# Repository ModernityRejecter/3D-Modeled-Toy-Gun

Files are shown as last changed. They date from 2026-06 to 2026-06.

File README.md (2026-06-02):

# 3D Printed Mechanical Blaster

A fully 3D-printable, **hammer-fired** mechanical toy blaster built around a two-piece press-fit case, a snap-locking side magazine, and **three entirely 3D-printed springs**. No metal hardware, no rubber bands - every functional part, including all springs, comes off the print bed.

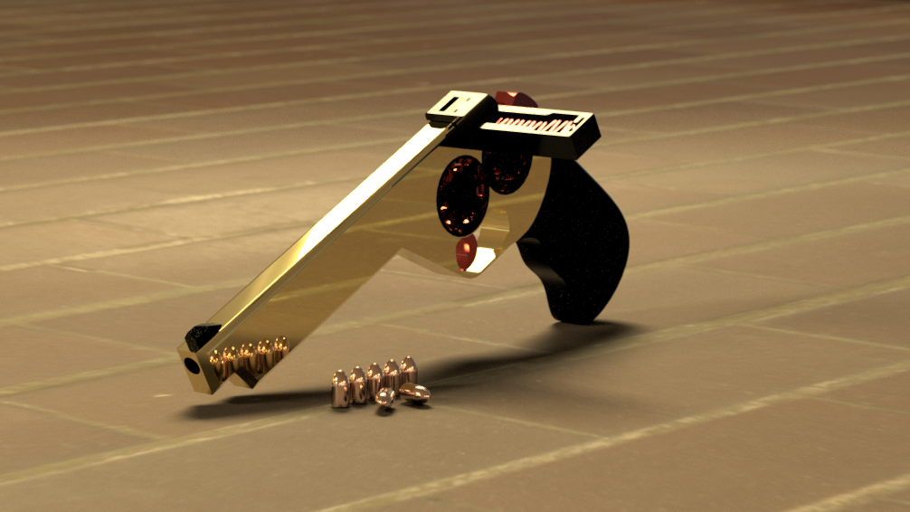
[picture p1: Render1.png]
Assembled blaster


## Project Description

This project is a hand-held, hammer-fired spring blaster that launches 3D-printed darts from a removable, spring-fed magazine. Energy is stored by winding a printed **spiral hammer spring**; pulling the trigger releases the hammer, which strikes a dart and fires it down the barrel. A printed **trigger-return spring** resets the trigger, and a printed **zig-zag magazine spring** feeds the next dart automatically.

What makes it notable: the entire mechanism - frame, barrel, hammer, trigger, magazine, darts, and **all three springs** - is 3D printed. The only thing between a spool of filament and a working blaster is print time and assembly.

The goal was to design a product that:
- **Serves a purpose** - IT'S FUN! It actually fires darts and reloads from a magazine, while doubling as a tactile fidget object.
- **Makes sense mechanically** - a wound spiral spring stores the firing energy; a sear/trigger releases it; a separate follower spring handles feeding.
- **Stays printable** - split into bed-friendly, snap-fit components with tuned tolerances so it prints with minimal supports.

## How It Works

The blaster's case is a **two-piece clamshell**, split along the centerline of the barrel into an **upper** and a **lower** half. Each half carries similar, mirrored features - half the barrel bore, the grip, and the internal cavities - and together they enclose the hammer, trigger and springs. The halves are held shut by **two snug press fits**, and a **detachable magazine** mounts on the side.

1. **Load the magazine.** Pull the follower down with your thumb and drop darts in through the skeletonized magazine's side feed-lips, against the zig-zag **magazine spring**, which keeps constant pressure so a fresh dart is always presented in line with the barrel.
2. **Insert the magazine.** It slides into the frame and a snap joint engages the upper case, locking it in place so it stays seated during firing until it is deliberately removed.
3. **Cock the hammer.** Cocking winds the spiral **hammer spring**, storing firing energy; a sear catches and holds the hammer.
4. **Fire.** Pulling the trigger releases the sear - the hammer snaps forward under the unwinding hammer spring and strikes the dart, launching it down the upper's barrel. The **trigger spring** returns the trigger to its resting position.
5. **Feed.** With the dart gone, the magazine spring advances the next dart into the barrel line. Because the magazine sits in-line as a *shoot-through breech*, there's no separate chambering step - it's ready to cock and fire again.

### Why it works
- **Spiral (clock-type) torsion springs** for the hammer and trigger store rotational energy compactly and spread the load along the whole coil - important for printed plastic, which takes a permanent set if a single section is over-stressed. Winding distributes strain so the spring survives repeated cycling.
- The **zig-zag magazine spring** is a linear, low-force accordion: long travel in a compact part, with gentle, consistent follower pressure that advances a dart without binding the feed.
- The **two-piece clamshell case** (split along the barrel centerline) lets the whole mechanism print support-free and gives full assembly access to the hammer, trigger and springs; the two halves then close over the internals with two snug press fits - no screws or glue.

## My Contribution & Design Philosophy

**The entire case - both the upper and the lower - is my own original creation, reimagined from the ground up.** The form factor, grip ergonomics, barrel layout, and the gold/black aesthetic are all mine; the case is not derived from any existing design.

What I drew from the two references below are the **functional building blocks**, which I then re-engineered so they could work *together* in one product:

- From the [**3D Printed Spring Blaster**](https://youtu.be/xOeDvl-vA04): the concept of a printed-spring-powered firing action, which I reworked into a wound spiral **hammer spring** plus a printed **trigger-return spring**.
- From the [**3D Printed Spring Gun with working Magazine**](https://youtu.be/UC8Zp1ZFvpY): the removable, spring-fed **magazine** and its zig-zag follower spring.

So the heavily-inspired elements are limited to the **three springs and the magazine** - everything that houses and connects them is original. Making a hammer-driven action and an auto-feeding magazine coexist meant rethinking how the hammer, sear, feed path, and three springs interact, since each reference solved only one half of the problem.

A detail I'm particularly proud of: **the magazine locks in place via a snap joint that engages the upper case** when inserted. It stays firmly seated during firing and only releases when deliberately removed - no wobble and no metal catch, fully printed.

## Design Journey

The final design is the result of real iteration. Two decisions shaped it more than any other: **how darts feed**, and **how the magazine stays locked**.

### Feeding system: from gravity hopper to side-mounted magazine

The first question was how to get a dart into the chamber. Several approaches were considered:

- **Vertical gravity hopper** - ruled out early. Hoppers are notoriously unreliable: tilt the blaster sideways or let darts clump together and gravity stops feeding, causing dry-fires. Worse, without constant pressure a dart can fall into the chamber half-seated just as the hammer swings forward, crushing it and jamming the action. A bulky top-mounted container would also have hidden the exposed spiral torsion spring that gives the blaster its mechanical character.
- **Bottom-feeding magazine** - rejected because it needs a complex transfer / lifter bar to raise rounds up to the barrel.
- **Horizontal feeding** - the winner. The choice came down to a sliding "harmonica" block versus a side-mounted ("Sten-style") magazine, and I went with the **side-mounted magazine**. It was worth troubleshooting the spring tension in exchange for the cool factor and the mechanical simplicity it unlocked: the swinging hammer doubles as **both the firing pin and the block that holds the next dart back**.

**The breakthrough** was treating the magazine as a physical extension of the barrel - a "shoot-through" / nested-breech layout. The dart fires straight through the magazine's feed position, which completely eliminates the need for a separate chambering mechanism.

**A course correction:** I first planned to reload darts backward through the front barrel hole of the magazine, but the geometry won't allow pushing darts in against the follower spring's pressure. The fix was a **skeletonized magazine** - open sides let you pull the follower down with your thumb and drop darts straight in through the side feed-lips.

### Magazine catch: from flex-latch to snap joint

With the magazine on the side, it had to stay put during firing. Three options were on the table:

- a **compliant flex-latch** (a printed living-hinge clip),
- a **manual pin** (padlock-style), and
- a simple **friction bump**.

The flex-latch was the most "engineered" route, and I even considered a durability trick: embedding a short piece of raw, unprinted **filament** as the bump so it would survive thousands of reloads without the plastic wearing down. In the end, though, the flex-latch/bump approach would have introduced **printing problems and a lot of support material for minimal gain**. So I swapped it for the **snap joint** the magazine uses today - it engages the upper case directly, locks firmly during firing, releases by hand, and prints cleanly with no supports.

## Renders

| | |
|---|---|
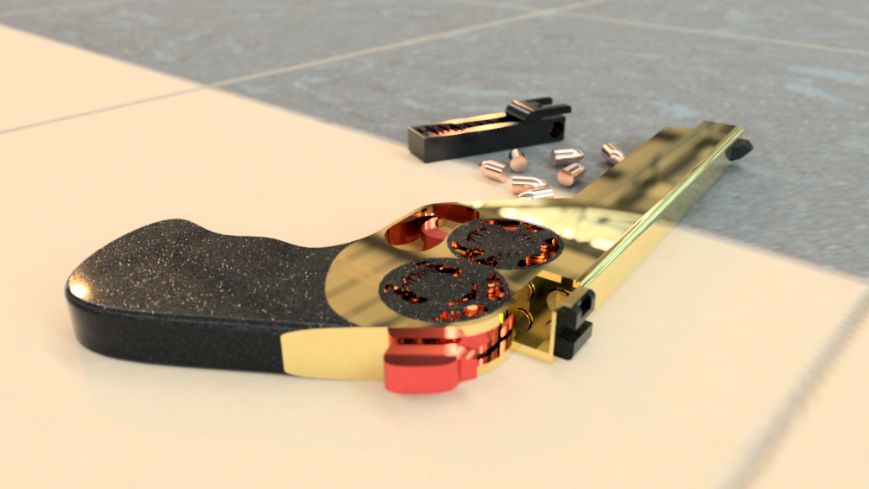
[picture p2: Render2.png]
Render 2
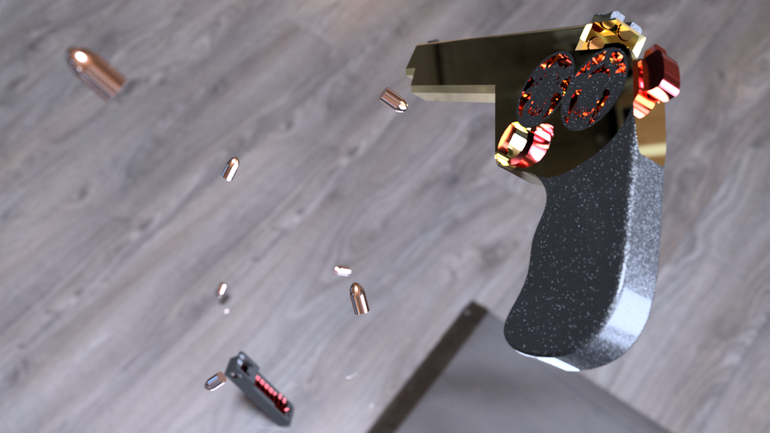
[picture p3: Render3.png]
Render 3
|  |  |

## Components & Parts

Every part is 3D printed. The mechanism comprises **7 unique components** (some printed in multiples), grouped below by the G-code file they belong to.

| Render | Component | Purpose | Print file |
|:---:|---|---|---|
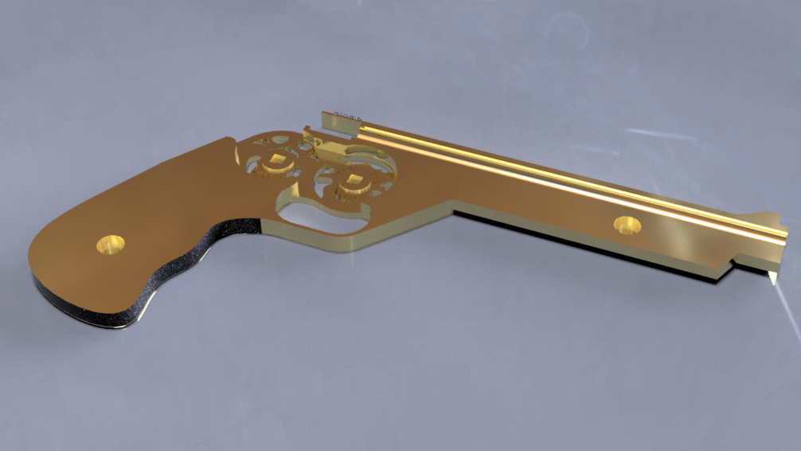
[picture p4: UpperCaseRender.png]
|  | **Upper case** | One half of the clamshell case (split along the barrel centerline). Carries half the barrel bore, grip and internal cavities, and encloses the hammer, trigger and springs together with the lower half. | `UpperCase.gcode` |
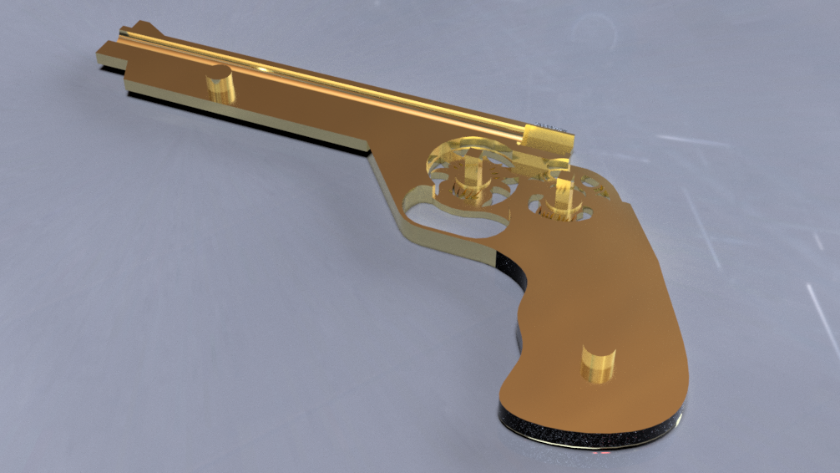
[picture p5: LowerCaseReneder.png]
|  | **Lower case** | The matching case half, with the mirrored half of the barrel, grip and trigger guard. Holds the hammer and trigger springs and accepts the side magazine; mates to the upper half via two snug press fits. | `LowerCase+TorsionSprings.gcode` |
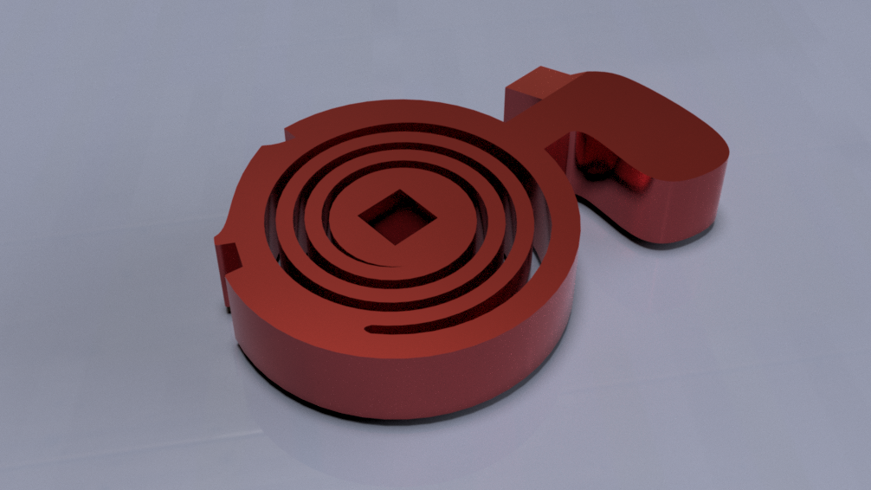
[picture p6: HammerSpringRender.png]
|  | **Hammer spring** | Spiral torsion spring with a square center mount. Wound during cocking; drives the hammer forward to strike the dart. | `LowerCase+TorsionSprings.gcode` |
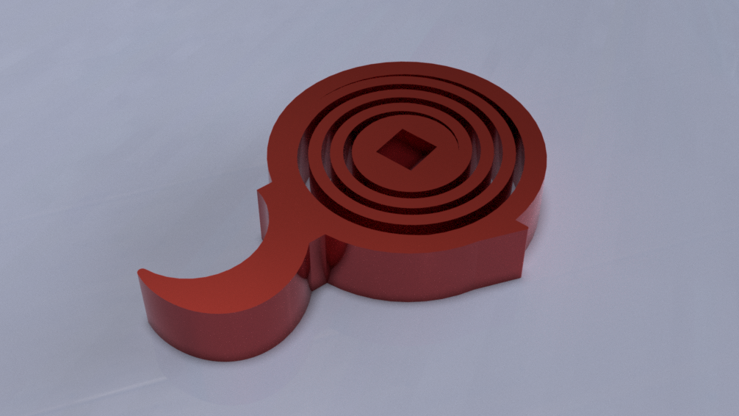
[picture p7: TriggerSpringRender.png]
|  | **Trigger spring** | Smaller spiral torsion spring; returns the trigger to its resting position and keeps the sear engaged. | `LowerCase+TorsionSprings.gcode` |
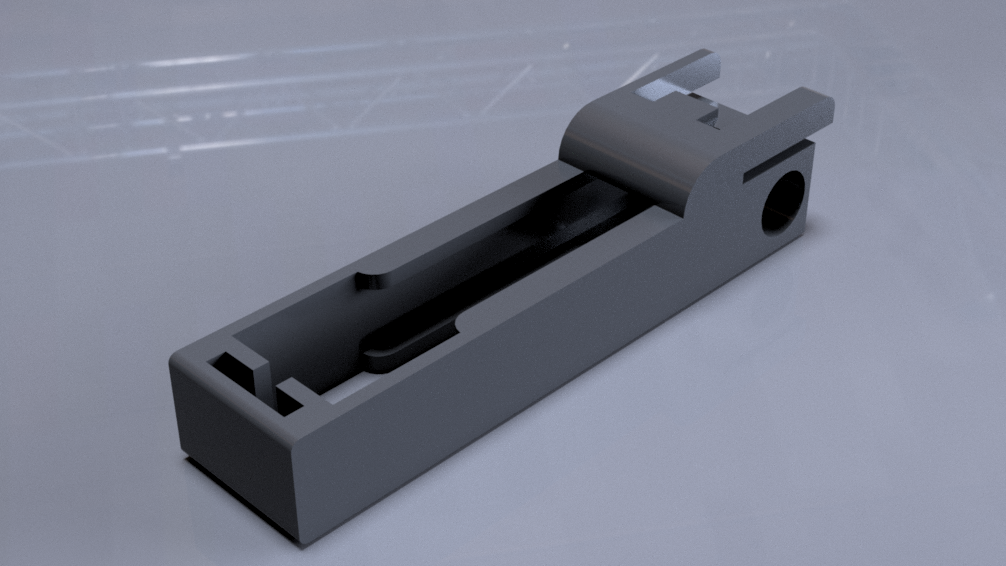
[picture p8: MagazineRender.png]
|  | **Magazine** | Detachable box magazine; holds the dart stack and guides rounds up to the feed position. Locks into the upper case via a snap joint when inserted. | `Darts+Mag+MagSpring.gcode` |
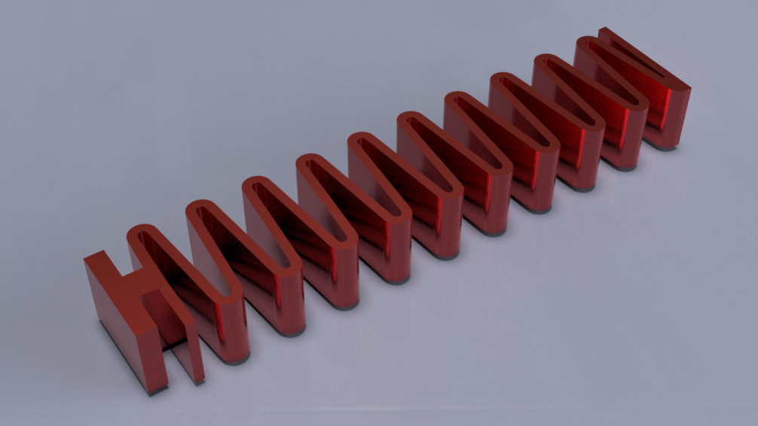
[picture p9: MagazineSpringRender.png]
|  | **Magazine spring** | Zig-zag (accordion) compression spring; the follower that pushes darts toward the chamber. | `Darts+Mag+MagSpring.gcode` |
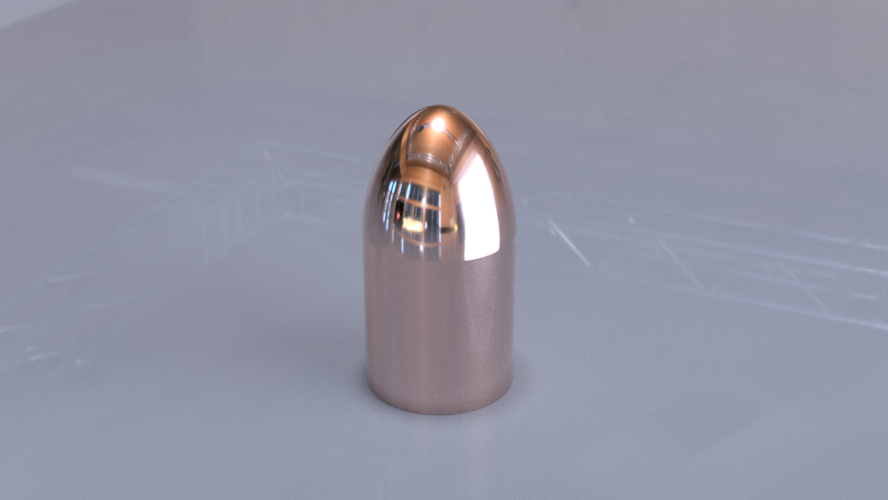
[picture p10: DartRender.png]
|  | **Dart** | The bullet-shaped projectile that the hammer strikes and launches. Printed in multiples. | `Darts+Mag+MagSpring.gcode` |

## Printability

The model was designed to be printed **without metal hardware or rubber bands, and with minimal supports**:

- **Split into bed-friendly components** - upper, lower, magazine, the three springs, and darts print separately so each fits a standard build plate and prints in its strongest orientation.
- **Press-fit + snap-fit assembly** - the two case halves hold together with two snug press fits and the magazine snap-locks to the case; no screws or glue required.
- **Three fully-printed springs** - the spiral hammer and trigger springs and the zig-zag magazine spring are the centerpiece of the printability story: their wall thicknesses and gaps are tuned so the plastic flexes and stores energy without snapping.
- **Tolerances** - mating/moving surfaces include clearance for FDM tolerances so the action moves freely straight off the printer.
- **Edges chamfered/filleted** for strength and to ease first-layer adhesion and part insertion.

## Video Showcase

▶️ **[Watch the assembly guide + motion-study showcase on YouTube](https://youtu.be/Alt_Uf0PqNY)**

Watch the demo (https://youtu.be/Alt_Uf0PqNY)

The video walks through how the blaster goes together and plays the Fusion 360 motion study, showing the hammer, trigger, and magazine feed in action.

## Project Files

| File | Description |
|---|---|
| [`ToyBlaster.f3d`](ToyBlaster.f3d) | Full Fusion 360 project (all components, sketches, joints, motion study) |
| [`ToyBlaster.stl`](ToyBlaster.stl) | Combined STL mesh of the model |
| [`UpperCase.gcode`](UpperCase.gcode) | Sliced G-code - upper / barrel |
| [`LowerCase+TorsionSprings.gcode`](LowerCase+TorsionSprings.gcode) | Sliced G-code - lower frame + hammer & trigger springs |
| [`Darts+Mag+MagSpring.gcode`](Darts+Mag+MagSpring.gcode) | Sliced G-code - darts, magazine, and magazine spring |
| Assembly renders | [`Render1.png`](Render1.png) · [`Render2.png`](Render2.png) · [`Render3.png`](Render3.png) |
| Component renders | [`UpperCaseRender.png`](UpperCaseRender.png) · [`LowerCaseReneder.png`](LowerCaseReneder.png) · [`HammerSpringRender.png`](HammerSpringRender.png) · [`TriggerSpringRender.png`](TriggerSpringRender.png) · [`MagazineRender.png`](MagazineRender.png) · [`MagazineSpringRender.png`](MagazineSpringRender.png) · [`DartRender.png`](DartRender.png) |

## Inspiration & Resources

This project was inspired by the following designs. Click an image to watch it in action:

3D Printed Spring Blaster (https://youtu.be/xOeDvl-vA04?si=E-KsS5-ckZ77c3AA)
**[3D Printed Spring Blaster](https://youtu.be/xOeDvl-vA04?si=E-KsS5-ckZ77c3AA)** - **merged philosophy #1:** the printed-spring firing action.

3D Printed Spring Gun with working Magazine (https://youtu.be/UC8Zp1ZFvpY?si=vRvTGaYKZ4BDErI3)
**[3D Printed Spring Gun with working Magazine](https://youtu.be/UC8Zp1ZFvpY?si=vRvTGaYKZ4BDErI3)** - **merged philosophy #2:** the removable, spring-fed magazine.

3D Printed Fidget Gun (https://youtu.be/0uawUImH5NA?si=HxQGf2qJCjkDknKz)
**[3D Printed Fidget Gun](https://youtu.be/0uawUImH5NA?si=HxQGf2qJCjkDknKz)** - general inspiration for the tactile / fidget feel.

**Tools used:** Autodesk Fusion 360 (modeling, joints, motion study) · PrusaSlicer (G-code generation) · Google Gemini (design sounding-board for evaluating the feeding and magazine-catch options) · Claude (Anthropic) (structuring and polishing this README).

## Design Challenges & Lessons Learned

The hardest parts of this project were all about making fully-printed mechanics behave reliably:

- **Tuning the three printed springs** was the biggest iteration cost. Wall thickness, gap spacing, and coil count all had to be balanced so each spring flexes and stores energy without snapping or taking a permanent set after repeated cycling. The spiral hammer and trigger springs and the zig-zag magazine spring each needed their own tuning.
- **Dialing in the snap-joint magazine lock** meant hitting a tight tolerance window on an FDM printer: firm enough that the magazine stays locked to the upper case during firing, loose enough that it still releases by hand. Too tight and it won't seat; too loose and it rattles out.
- **Making the hammer action and magazine feed coexist** was the core mechanical problem - the hammer had to strike and clear the chamber on every cycle without the follower spring fouling its travel, which is what drove the internal layout and the placement of the three springs.
- **Designing for printability from the start** - splitting the model into bed-friendly, snap-fit parts and orienting each for strength and minimal supports - was far easier than trying to retrofit printability onto a finished design.

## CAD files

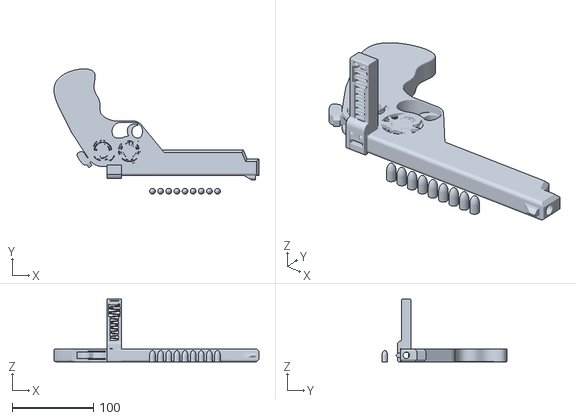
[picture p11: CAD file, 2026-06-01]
ToyBlaster.stl
252.2 x 154.1 x 77.0

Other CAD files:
ToyBlaster.f3d

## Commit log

2026-05-28 Modeled torsion springs and started sketching chassis
    [ToyBlaster.f3d]
2026-06-01 Added gcode files and renders
    [ToyBlaster.f3d, ToyBlaster.stl]
